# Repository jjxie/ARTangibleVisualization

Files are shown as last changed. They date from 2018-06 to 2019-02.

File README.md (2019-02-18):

# Augmented physical visualization of home food consumption and nutrition

## Introduction
In this project, I took the context of tracking the amount of personal food consumption and nutrient intakes as the scenario for exploring a new interface and interactions with the help of connected sensors, actuators, and augmented reality (AR). The novel tangible interface consists of two physical data representations with overlay AR information, respectively present the amount of food weight and nutrients intake. To compare how well the tangible interface performs in helping people in the context of gaining insight from the amount of food consumption and nutrients intake, a comparable screen interface is designed and developed. The screen interface is a webpage on the desktop with the same functionalities as the tangible interface, but with different interactions.
<br/>Check here for detailed information: https://jjxie8.wixsite.com/thinkbig/master-thesis-project.

## The settings of the project
This Project runs Socket IO client sides on two ESP32 boards and server side on the index.js.<br />Keywords: Socket.io, Arduino IDE, Webcam, A-Frame, AR.js Marker Trainning, Javascript, Bootstrap, Chart.js, Sketch 3D printing / Laser cutting, Card boards.

The sensors and materials used:
- Three ESP32 boards. 
- Five load cells and five HX711 amplifiers to measure food weight.
- Ten linear servos (SG90) + ten 3D models. Five sets represent food weight. Another five sets represent the amount of daily nutrients intake. The height of a rack of a 3D model represent a food weight data or the amount of a nutreint intake. 
The 3D model files from https://github.com/tscha70/3DPrinterSTLFiles/tree/master/win-D/STL-Parts with minor modifications.
- Five touch sensors are used to do selection of food to show detailed AR information. (using AR.js) 
- Five distance sensors (VL6180) which enable users to interact with the food weight data and see the simulated food consumption and nutrition intakes 

## Video prototype
- A video of the tangible interface prototype on Youtube: <br /> 
<a href="http://www.youtube.com/watch?feature=player_embedded&v=QyQpSfhoo6U
" target="_blank">The tangible interface</a>          
- A video of comparing screen interface prototype on Youtube: <br/>
 <a href="http://www.youtube.com/watch?feature=player_embedded&v=5_SD-PaekHA
" target="_blank">The screen interface</a>

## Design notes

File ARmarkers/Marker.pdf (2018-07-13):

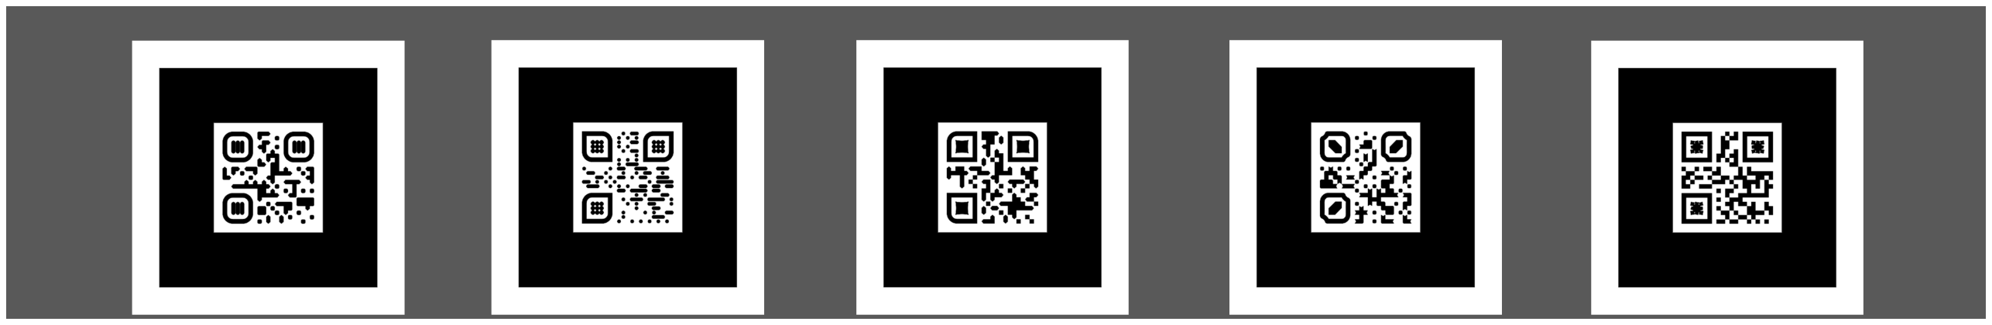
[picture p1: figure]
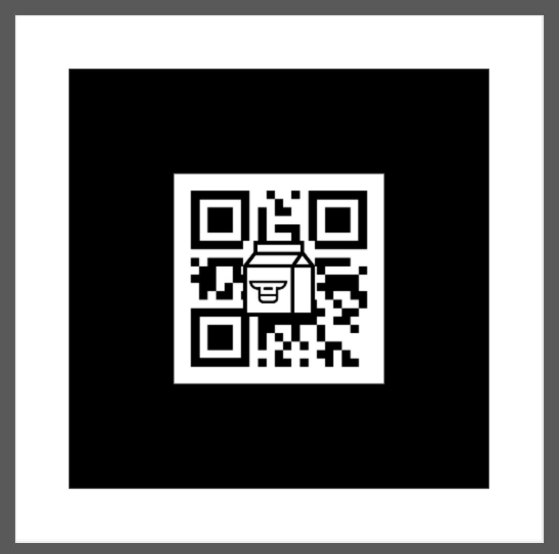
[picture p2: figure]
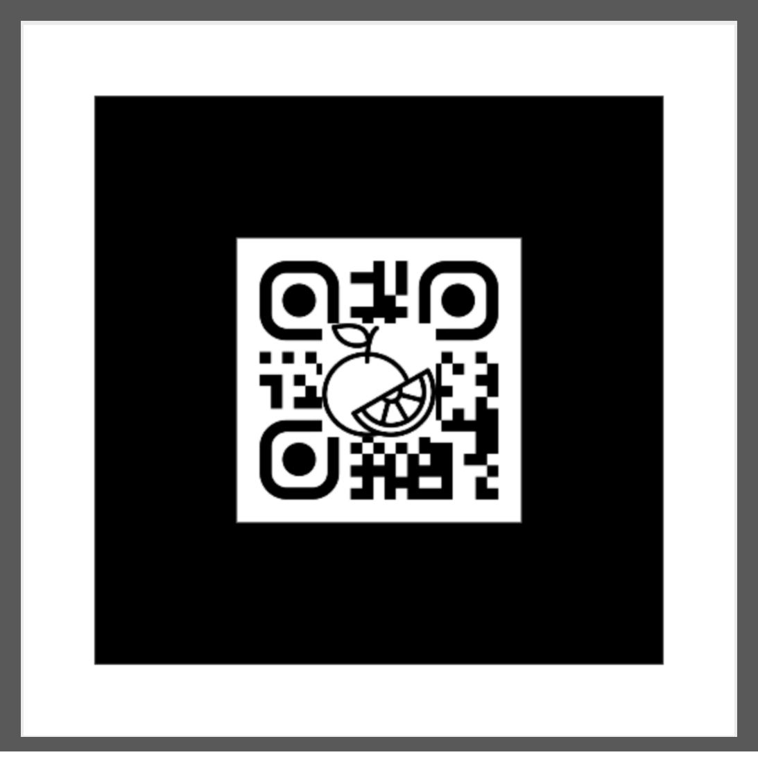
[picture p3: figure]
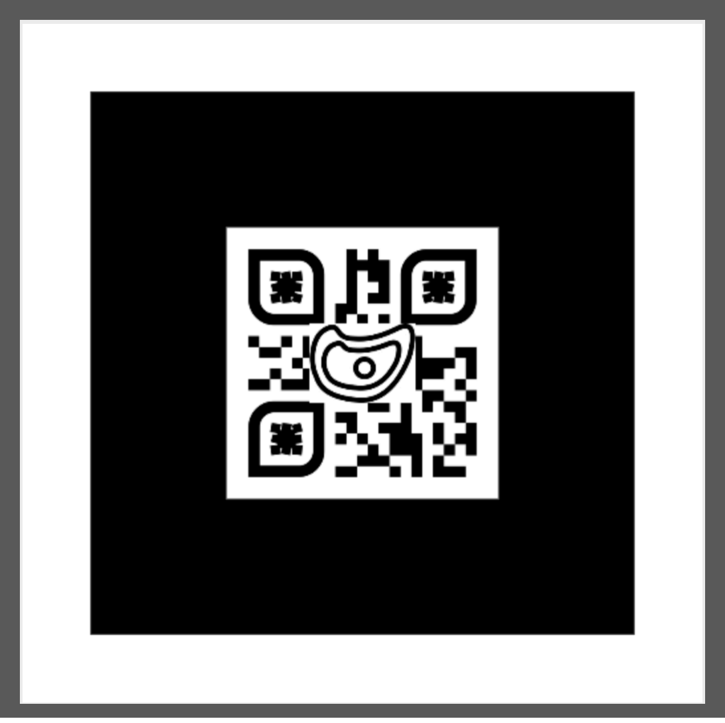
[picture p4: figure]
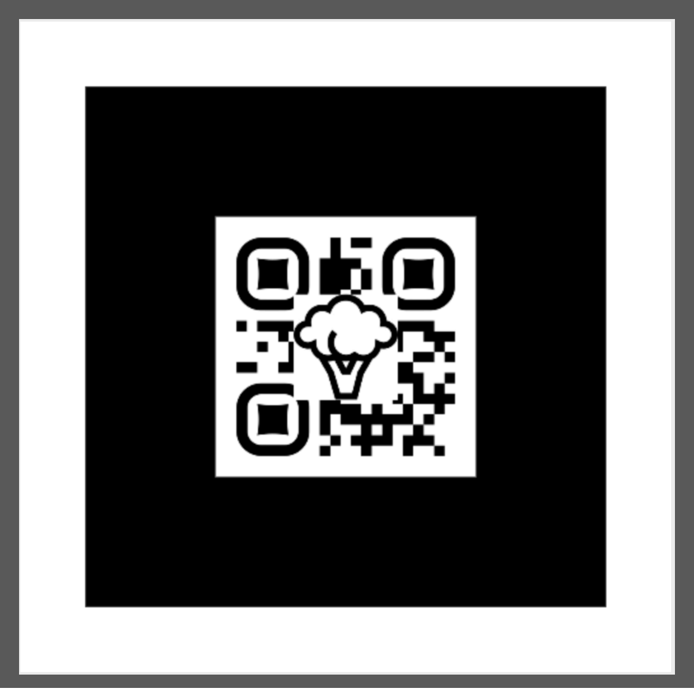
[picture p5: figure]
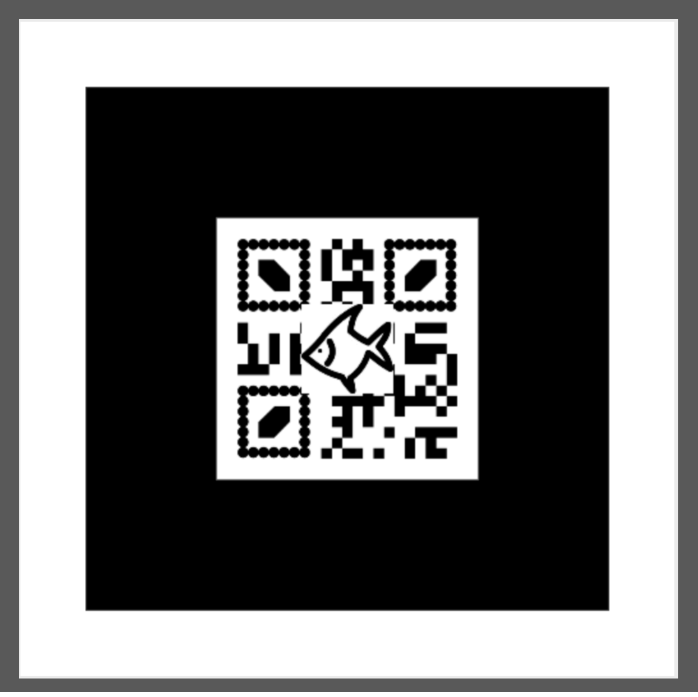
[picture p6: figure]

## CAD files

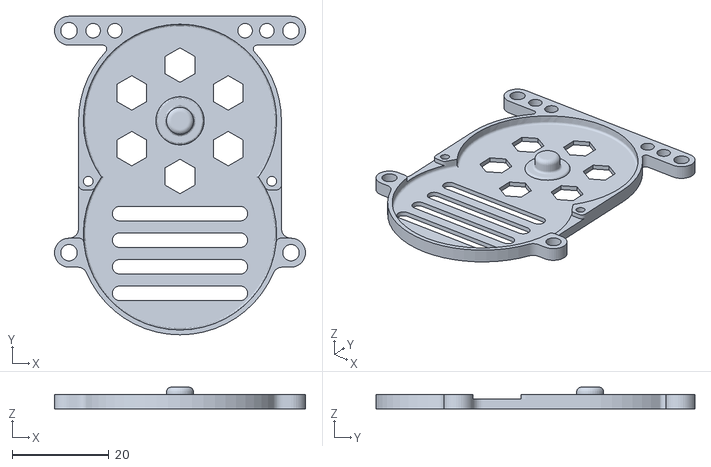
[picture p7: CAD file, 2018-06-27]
3D printing/wind-D_topplate.STL
52.0 x 65.9 x 4.50

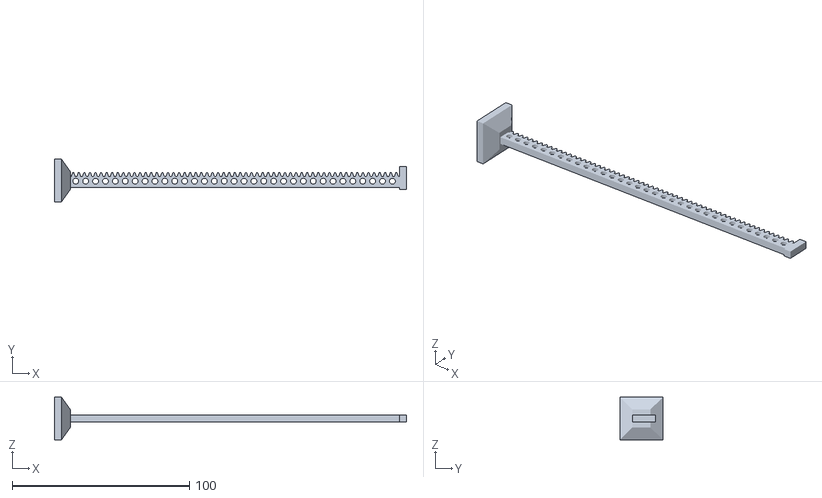
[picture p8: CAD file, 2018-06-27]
3D printing/rack1.stl
198.5 x 24.0 x 24.0

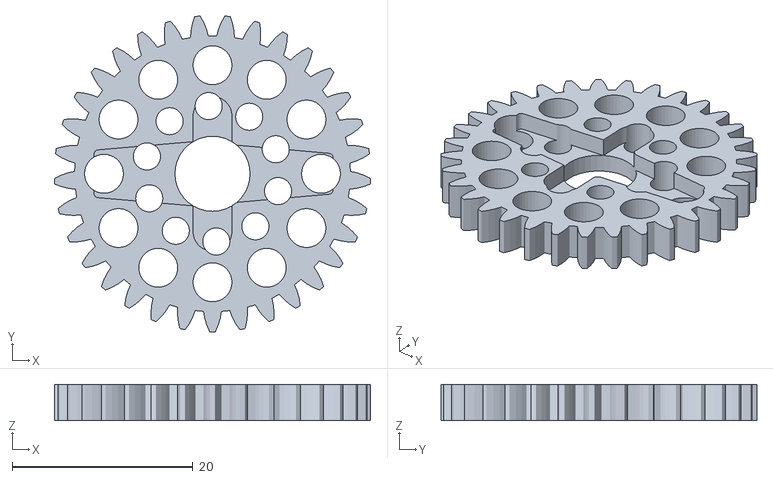
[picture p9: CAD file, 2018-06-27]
3D printing/wind-D_Gear33-1M-4mm_Servo.STL
35.0 x 34.9 x 4.00

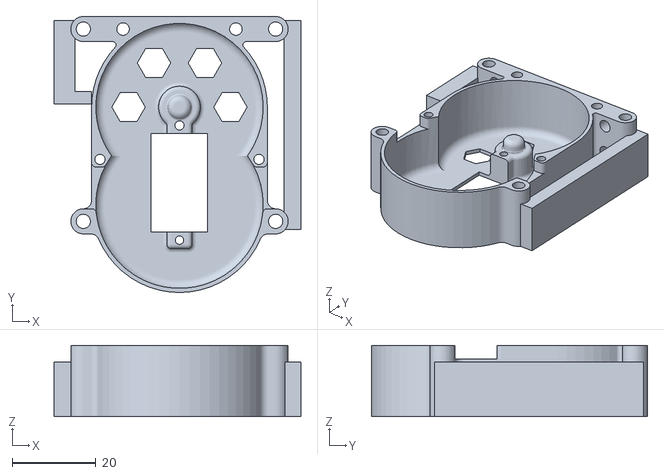
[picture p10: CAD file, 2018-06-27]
3D printing/base.stl
59.0 x 65.9 x 17.0

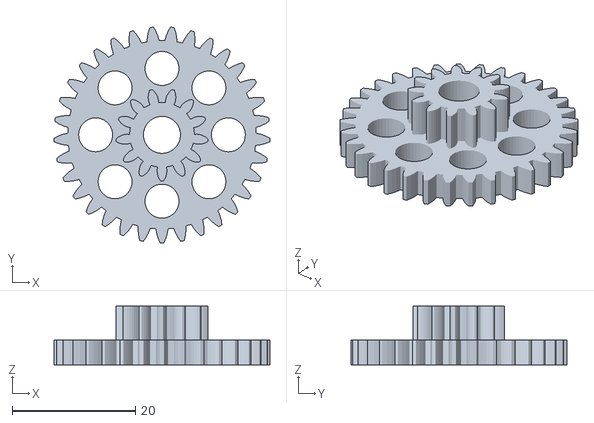
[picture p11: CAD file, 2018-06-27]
3D printing/wind-D_GearNormal.STL
35.0 x 34.9 x 9.50

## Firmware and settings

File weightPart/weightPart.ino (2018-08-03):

/******************************************************************************
   SparkFun_VL6180X, https://github.com/sparkfun/SparkFun_ToF_Range_Finder-VL6180_Arduino_Library

   Multiple VL6180 solution from https://learn.sparkfun.com/tutorials/vl6180-hookup-guide/discuss
   Add _i2caddress = new_address; to in Sparkfun_VL6180X.cpp in here:
   … VL6180x_setRegister(VL6180X_I2C_SLAVE_DEVICE_ADDRESS, new_address); i2caddress = new_address;
   return VL6180x_getRegister(VL6180X_I2C_SLAVE_DEVICE_ADDRESS); }

   Add one Euro filter to reduce distance reading jitter, http://cristal.univ-lille.fr/~casiez/1euro/

   SocketIoClient, have to comment // hexdump(payload, length); in the SocketIoClient.cpp file to avoid error.
   I2C: SDA 21  SCL 22

   Secure SSL connection, Socket.beginSSL("192.168.0.100", 3000);
 ******************************************************************************/
#define ESP32
#include <SocketIoClient.h>

#include <SF1eFilter.h>
#include <stdlib.h>
#include <time.h>
#include <stdio.h>
#include <Wire.h>
#include <math.h>
#include <ESP32_Servo.h>
#include <WiFi.h>

// The Router that the board connects to
const char* ssid = "TP-LINK_8F96";
const char* password = "49005875";

// socket.io connection
SocketIoClient socket;


// Published values for SG90 servos; adjust if needed
int minUs = 500;
int maxUs = 2400;

Servo servoMilk;
Servo servoOrange;
Servo servoMeat;
Servo servoBroccoli;
Servo servoFish;

// Define servo pins
int milkServoPin = 23;
int orangeServoPin = 18;
int meatServoPin = 27;
int broccoliServoPin = 32;
int fishServoPin= 12;

int servoStartDegree = 0;
float maxWeight = 1000;

// The full length of each servo
float servoMilkFullLength = 13.4;
float servoOrangeFullLength = 12.3;
float servoMeatFullLength = 12.3;
float servoBrocolliFullLength = 12.3;
float servoFishFullLength = 11.9;

// The length of per degree
float servoMilkLengthPerDegree = 0.087;
float servoOrangeLengthPerDegree = 0.072;
float servoMeatLengthPerDegree = 0.072;
float servoBrocolliLengthPerDegree = 0.072;
float servoFishLengthPerDegree = 0.06;

// The max degree of each servo
float servoMilkMaxDegree = 160;
float servoOrangeMaxDegree = 170;
float servoMeatMaxDegree = 170;
float servoBrocolliMaxDegree = 170;
float servoFishMaxDegree = 180;

// The received weight data
float milkWeight = 0.00;
float orangeWeight = 0.00;
float meatWeight = 0.00;
float brocolliWeight = 0.00;
float fishWeight = 0.00;

// The calculated degree
float milkDegree = 0.00;
float orangeDegree = 0.00;
float meatDegree = 0.00;
float brocolliDegree = 0.00;
float fishDegree = 0.00;


// Define touch sensor pins
int milkTouchPin = 19;
int orangeTouchPin = 17;
int meatTouchPin = 35;
int broccoliTouchPin = 33;
int fishTouchPin= 13;

// Selection status
boolean milkSelected = false;
boolean orangeSelected = false;
boolean meatSelected = false;
boolean broccoliSelected = false;
boolean fishSelected = false;

static unsigned long lastMillis = 0;


void setup() {
  // put your setup code here, to run once:
  Serial.begin(115200);
  Wire.begin();
  delay(100);

  // connect to wifi rounter in the environment
  Serial.print("Connecting to WiFi network ");
  Serial.println(ssid);
  WiFi.begin(ssid, password);
  while (WiFi.status() != WL_CONNECTED) {
    Serial.print(".");
    delay(500);
  }
  Serial.println("");
  Serial.println("Connected to the WiFi network");
  Serial.println("IP address: ");
  Serial.println(WiFi.localIP());

  // Begin a secure socket, find your computer WiFi TCP/IP Address
  // Mac Network--> WiFi--> Advanced--> TCP/IP 192.168.0.101
  socket.beginSSL("192.168.0.101", 3000);
  delay(100);

  socket.on("connect", socketConnected);

  // Servos
  servoMilk.attach(milkServoPin, minUs, maxUs);
  servoOrange.attach(orangeServoPin, minUs, maxUs);
  servoMeat.attach(meatServoPin, minUs, maxUs);
  servoBroccoli.attach(broccoliServoPin, minUs, maxUs);
  servoFish.attach(fishServoPin,minUs, maxUs);

  servoMilk.write(servoStartDegree);
  servoOrange.write(servoStartDegree);
  servoMeat.write(servoStartDegree);
  servoBroccoli.write(servoStartDegree);
  servoFish.write(servoStartDegree);


  // Touch sensors
  pinMode(milkTouchPin, INPUT);
  pinMode(orangeTouchPin, INPUT);
  pinMode(meatTouchPin, INPUT);
  pinMode(broccoliTouchPin, INPUT);
  pinMode(fishTouchPin, INPUT);

  delay(100);
}

void loop()
{
  socket.loop();
  socket.on("connect", socketConnected);
  
  // Receive milk weight data and rotate servo
  socket.on("scaleDataMilk", setMilkServo);
  // Receive orange weight data, rotate servo
  socket.on("scaleDataOrange", setOrangeServo);
  // Receive meat weight data, rotate servo
  socket.on("scaleDataMeat", setMeatServo);
  // Receive broccoli weight data, rotate servo
  socket.on("scaleDataBroccoli", setBroccoliServo);
  // Receive fish weight data, rotate servo
  socket.on("scaleDataFish", setFishServo);

  // Read milk touch sensor pins, emit 1 when touch the sensor
  boolean milkTouch = digitalRead(milkTouchPin);
  if (milkTouch != milkSelected) {
    milkSelected = milkTouch;
    if (milkTouch) socket.emit("milk", "\"1\"");
  }
  // Read orange touch sensor pins value and set status
  boolean orangeTouch = digitalRead(orangeTouchPin);
  if (orangeTouch != orangeSelected) {
    orangeSelected = orangeTouch;
    if (orangeTouch) socket.emit("orange", "\"1\"");
  }
  // Read meat touch sensor pins value and set status
  boolean meatTouch = digitalRead(meatTouchPin);
  if (meatTouch != meatSelected) {
    meatSelected = meatTouch;
    if (meatTouch) socket.emit("meat", "\"1\"");
  }
  // Read broccoli touch sensor pins value and set status
  boolean broccoliTouch = digitalRead(broccoliTouchPin);
  if (broccoliTouch != broccoliSelected) {
    broccoliSelected = broccoliTouch;
    if (broccoliTouch) socket.emit("broccoli", "\"1\"");
  }
  // Read fish touch sensor pins value and set status
    boolean fishTouch = digitalRead(fishTouchPin);
    if (fishTouch != fishSelected) {
      fishSelected = fishTouch;
      if (fishTouch) socket.emit("fish", "\"1\"");
    }

}


// Calculate the rotate degree based on (received weight data, the full length of the servo rack, the length per degree of the servo)
float calDegree(float weight, float fullLength, float lenghPerDegree) {
  float degree = round((weight / maxWeight * fullLength) / lenghPerDegree + 0.5);
  return degree;
}


// Socket IO functions
void socketConnected(const char *message, size_t length) {
  Serial.println("Board connects to server now!");
}

// Convenience functions to set servos; these are used as callbacks for the socket.io messages
void setMilkServo(const char *weight, size_t length) {
  servoMilk.attach(milkServoPin, minUs, maxUs);
  // get value from message
  String data;
  for (int i = 0; i < length; i++) {
    data += (char)weight[i];
  }
  int value = data.toInt();

  // calculate value for servo and send it
  float transformedValue = calDegree(value, servoMilkFullLength, servoMilkLengthPerDegree);
  //  attachAndSetServo(servoMilk,milkServoPin,transformedValue);
  Serial.print(value);
  Serial.print("  ");
  Serial.println(transformedValue);
  servoMilk.write(transformedValue); 
  delay(3000);
  servoMilk.detach();
}

void setOrangeServo(const char *weight, size_t length) {
  servoOrange.attach(orangeServoPin, minUs, maxUs);
  // get value from message
  String data;
  for (int i = 0; i < length; i++) {
    data += (char)weight[i];
  }
  int value = data.toInt();

  // calculate value for servo and send it
  float transformedValue = calDegree(value, servoOrangeFullLength, servoOrangeLengthPerDegree);
  //  attachAndSetServo(servoMilk,milkServoPin,transformedValue);
  Serial.print(value);
  Serial.print("  ");
  Serial.println(transformedValue);
  servoOrange.write(transformedValue);
  delay(3000);
  servoOrange.detach();
}

// Convenience functions to set servos; these are used as callbacks for the socket.io messages
void setMeatServo(const char *weight, size_t length) {
  servoMeat.attach(meatServoPin, minUs, maxUs);
  // get value from message
  String data;
  for (int i = 0; i < length; i++) {
    data += (char)weight[i];
  }
  int value = data.toInt();

  // calculate value for servo and send it
  float transformedValue = calDegree(value, servoMeatFullLength, servoMeatLengthPerDegree);
  Serial.print(value);
  Serial.print("  ");
  Serial.println(transformedValue);
  servoMeat.write(transformedValue);
  delay(3000);
  servoMeat.detach();
}

void setBroccoliServo(const char *weight, size_t length) {
  servoBroccoli.attach(broccoliServoPin, minUs, maxUs);
  // get value from message
  String data;
  for (int i = 0; i < length; i++) {
    data += (char)weight[i];
  }
  int value = data.toInt();

  // calculate value for servo and send it
  float transformedValue = calDegree(value, servoBrocolliFullLength, servoBrocolliLengthPerDegree);
  Serial.print(value);
  Serial.print("  ");
  Serial.println(transformedValue);
  servoBroccoli.write(transformedValue);
  delay(3000);
  servoBroccoli.detach();
}

void setFishServo(const char *weight, size_t length) {
  servoFish.attach(fishServoPin, minUs, maxUs);
  // get value from message
  String data;
  for (int i = 0; i < length; i++) {
    data += (char)weight[i];
  }
  int value = data.toInt();

  // calculate value for servo and send it
  float transformedValue = calDegree(value, servoFishFullLength, servoFishLengthPerDegree);
  Serial.println(transformedValue);
  servoFish.write(transformedValue);
  delay(3000);
  servoFish.detach();
}

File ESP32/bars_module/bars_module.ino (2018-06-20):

#define ESP32

#include <SparkFun_VL6180X.h>


#include <SocketIoClient.h>


#include <Wire.h>
#include <math.h>
#include <ESP32_Servo.h>


#include <WiFi.h>
const char* ssid = "TP-LINK_8F96";
const char* password = "49005875";

// comment the distance sensors out as long as their are not connected
//#define VL6180X_ADDRESS 0x29
//VL6180xIdentification identification;
//VL6180x sensor(VL6180X_ADDRESS);


// socket.io connection
SocketIoClient socket;


Servo servoMilk;
Servo servoOrange;
Servo servoMeat;
Servo servoBroccoli;
Servo servoFish;

int servoStartDegree = 0;
float maxWeight = 1000;

// The full length of each servo
float servoMilkFullLength = 13.4;
float servoOrangeFullLength = 12.3;
float servoMeatFullLength = 12.3;
float servoBrocolliFullLength = 12.3;
float servoFishFullLength = 11.9;

// The length of per degree
float servoMilkLengthPerDegree = 0.087;
float servoOrangeLengthPerDegree = 0.072;
float servoMeatLengthPerDegree = 0.072;
float servoBrocolliLengthPerDegree = 0.072;
float servoFishLengthPerDegree = 0.06;

// The max degree of each servo
float servoMilkMaxDegree = 160;
float servoOrangeMaxDegree = 170;
float servoMeatMaxDegree = 170;
float servoBrocolliMaxDegree = 170;
float servoFishMaxDegree = 180;

// The received weight data
float milkWeight = 0.00;
float orangeWeight = 0.00;
float meatWeight = 0.00;
float broccoliWeight = 0.00;
float fishWeight = 0.00;

// The calculated degree
float milkDegree = 0.00;
float orangeDegree = 0.00;
float meatDegree = 0.00;
float broccoliDegree = 0.00;
float fishDegree = 0.00;

// The servo pins
int milkServoPin = 8;
int orangeServoPin = 9;
int meatServoPin = 10;
int broccoliServoPin = 11;
int fishServoPin = 12;
 

// Define touch sensor pins
int milkTouchPin = 2;
int orangeTouchPin = 3;
int meatTouchPin = 4;
int broccoliTouchPin = 5;
int fishTouchPin = 6;

// Touch sensor value
int milkTouchValue = 0;
int orangeTouchValue = 0;
int meatTouchValue = 0;
int broccoliTouchValue = 0;
int fishTouchValue = 0;

// Touch sensor status
boolean milkSelected = false;
boolean orangeSelected = false;
boolean meatSelected = false;
boolean broccoliSelected = false;
boolean fishSelected = false;


// Distance
float milkRackDistance = 0.00;
float orangeRackDistance = 0.00;
float meatRackDistance = 0.00;
float broccoliRackDistance = 0.00;
float fishRackDistance = 0.00;

boolean servosConnected = false;

void setup() {
  // put your setup code here, to run once:
  Serial.begin(57600);
  delay(10);
    Serial.print("Connecting to WiFi network ");
    Serial.println(ssid);
  WiFi.begin(ssid, password);
  while (WiFi.status() != WL_CONNECTED) {
    Serial.print(".");
    delay(500);
  }
  Serial.println("");
  Serial.println("Connected to the WiFi network");
  Serial.println("IP address: ");
  Serial.println(WiFi.localIP());
  // the above line is the last one that is printed out on the serial monitor before the kernel panic

  
  Wire.begin();
  socket.begin("192.168.0.100", 3000);
  delay(100);

  //sensor.getIdentification(&identification); // Retrieve manufacture info from device memory
  //printIdentification(&identification); // Helper function to print all the Module information

  // Setting Distance sensor 
  //if(sensor.VL6180xInit() != 0){
  //  Serial.println("FAILED TO INITALIZE"); //Initialize device and check for errors
  //}; 
  //sensor.VL6180xDefautSettings(); //Load default settings to get started.
  //delay(1000); // delay 1s

  // Servos
  if (servosConnected){
  servoMilk.attach(8);
  servoOrange.attach(9);
  servoMeat.attach(10);
  servoBroccoli.attach(11);
  servoFish.attach(12);
  
  servoMilk.write(servoStartDegree);
  servoOrange.write(servoStartDegree);
  servoMeat.write(servoStartDegree);
  servoBroccoli.write(servoStartDegree);
  servoFish.write(servoStartDegree);
  }

  // Touch sensors
  pinMode(milkTouchPin, INPUT); 
  pinMode(orangeTouchPin, INPUT); 
  pinMode(meatTouchPin, INPUT); 
  pinMode(broccoliTouchPin, INPUT); 
  pinMode(fishTouchPin, INPUT); 

  // define socket io callbacks
  socket.on("connect", socketConnected);
  socket.on("scaleDataMilk", setMilkServo);
  //TODO: uncomment after functions are implemented
//  socket.on("scaleDataOrange", setOrangeServo);
//  socket.on("scaleDataMeat", setMeatServo);
//  socket.on("scaleDataBroccoli", setBroccoliServo);
//  socket.on("scaleDataFish", setFishServo);

}

void loop() 
{ 
  socket.loop();
  // we need to read the touch sensors and emit a socket.io message if a status changes
  boolean milk = digitalRead(milkTouchPin);
  if (milk != milkSelected) {
    milkSelected = milk;
    if (milk) socket.emit("Milk selection status", "\"1\"");
    if (!milk) socket.emit("Milk selection status", "\"0\"");
  }

  //TODO: do the same for the other 4 sensors























  // Read distance sensors, probably needs to use i2c addresses to indicate which sensor to query.
//  milkRackDistance =  sensor.getDistance();

}


// Calculate the degree based on 
// received weight data, the full length and the length per degree of the servo
float calDegree(float weight, float fullLength, float lenghPerDegree){
  float degree = round((weight/maxWeight * fullLength) / lenghPerDegree + 0.5);
  return degree;
}

// Convenience functions to set servos; these are used as callbacks for the socket.io messages
void setMilkServo(const char *weight, size_t length){
  // get value from message
  String data;
  for (int i = 0; i < length; i++) {
    data += (char)weight[i];
  }
  int value = data.toInt();

  // calculate value for servo and send it
  float transformedValue = calDegree(value, servoMilkFullLength, servoMilkLengthPerDegree);
  attachAndSetServo(servoMilk, milkServoPin, transformedValue);
}




//TODO: add functions for orange, meat, broccoli and fish



























void attachAndSetServo(Servo servo, int pin, int value) {
  servo.attach(pin);
  servo.write(value);
  servo.detach();
}


void socketConnected(const char *weight, size_t length){
  // get value from message
  Serial.println("Socket.io server connected.");
}

const char* printBoolean(boolean input){
  if (input) return("1");
  if (!input) return("0");
}

void printIdentification(struct VL6180xIdentification *temp){
  Serial.print("Model ID = ");
  Serial.println(temp->idModel);

  Serial.print("Model Rev = ");
  Serial.print(temp->idModelRevMajor);
  Serial.print(".");
  Serial.println(temp->idModelRevMinor);

  Serial.print("Module Rev = ");
  Serial.print(temp->idModuleRevMajor);
  Serial.print(".");
  Serial.println(temp->idModuleRevMinor);  

  Serial.print("Manufacture Date = ");
  Serial.print((temp->idDate >> 3) & 0x001F);
  Serial.print("/");
  Serial.print((temp->idDate >> 8) & 0x000F);
  Serial.print("/1");
  Serial.print((temp->idDate >> 12) & 0x000F);
  Serial.print(" Phase: ");
  Serial.println(temp->idDate & 0x0007);

  Serial.print("Manufacture Time (s)= ");
  Serial.println(temp->idTime * 2);
  Serial.println();
  Serial.println();
}

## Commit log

2018-03-28 Combine socket io with sensor data
2018-03-28 1. Support show sensor data on clients side when client is connected 2. Cannot real external css file
2018-03-28 Add a progress bar, the width value change based on sensor data
2018-03-28 1. Add a second sensor, and track its data 2. Change the style of progress of the first sensor
2018-03-29 1. Add a controller and its color is controlled by three other controllers 2. When a new client is connected, sometimes the sensor data will stuck, console has error setcolor is undefined, will check
    [index.js]
2018-03-30 1. Working prototype
2018-04-06 Change the variable name of sensor part to make it clear
2018-04-17 1. Connect wemos D1 mini with JS 2. Use Webduino sensor data control the blink frequency of wemos 3. Comment some interface code 4. Add AR markers file
2018-05-17 Change the client side with Arduino board. Keep the Wemos board code
2018-05-22 Add touch sensor data and AR view changes
    1. Add touch sensor part
    2. AR view changes according to the touch sensor as select or deselect
    data point
2018-05-22 Add touch sensor code and switch webduino to router wifi
2018-05-29 Serialport
    Adding serialport to the code, so can read Wemos serial data and broadcast this data using socket io.
2018-06-05 Broadcasting weight data
    Receive sensor data from wemos through serial port, and then broadcast the data to with different name to client(Arduino board) and html(AR)
2018-06-08 connect servo with calibration of the degree data
2018-06-12 Adding scale arduino data with one Euro filter
    Uploading arduino code which is run on Wemos D1 mini with four HX711+ load cell connected.
2018-06-13 Add arduino code
    1. the distance sensor part doesn't work.
    2. Add a test under loop Milk touch sensor
    [client.js]
2018-06-13 added code for esp32
2018-06-14 Scale arduino code update
    1. Each servo data has it's own 1 euro filter structure
    2. Chage the serial.begin
    3. Cancel delay between each servo read.
    4. Add logic, when data changes more than 3, then read more data. If two sequence readed data difference is smaller than 1, then regard this data as current weight data, serial print.
2018-06-18 Add mulitiple distance sensors with One euro filter
2018-06-20 arduino file for the ESP32 boards
    There are several todo items left to implement functions for the other food items.
    The board crashes and reboots after the wifi connection is established. Needs debugging.
    [bars_module.ino]
2018-06-21 ESP32 Socket io
    1. Connect ESP32 board with index.js
    2. Webcam is not working due to serve change to 192.168.0.100:3000, not secure.
    [index.js]
2018-06-22 Arduino socket io. Revise touch sensor and servo code
2018-06-26 Switch to secure connection and Weight Socket
    1. Switch to https
    2. Change to Socket.io to transfer weight data
2018-06-27 Scale arduino side can emit string data to server side
2018-06-27 Add servo range
    1. Add servo range which could let servo reach to right position. Without minUs and maxUs, the servo reach to wired position, like write(0), not in zero position.
    2. Distance sensors are not working. Sometimes can work. Need to check.
2018-06-27 Upload 3D models which work with Servos
    [base.stl, rack1.stl, wind-D_Gear33-1M-4mm_Servo.STL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]
2018-07-02 Add check to zero and jitter data in index.js
    [index.js]
2018-07-03 Slow down the ESP32 CPU in order to get stable weight data
    It is said from a post that the ESP32 is too fast for HX711, thus will output wierd data. After slow down the CPU, althoug the board processes much slower, but the data is much more accurate and stable. The resources: https://github.com/bogde/HX711/issues/75
2018-07-03 delay long before detach servo and calculate weight with distance data
2018-07-04 Add manually change weight code and seperate AR code
    1. Add manually changing weight code in both arduino and sever side. And show the new data on html
    2. Seperate AR and progress bar parts into two separate htmls. Preparing for testing.
2018-07-15 Nutrition calculate and save to history, add fish
    1. Add detection of day turning at midnight. Save current nutrition array data and yesterday to history json file, and then re intial nutrition array for the new day.
    2. Add fish parts code.
2018-07-18 Fix bug of showing virtual nutrients bar
    [index.js]
2018-07-18 Add a reset virtual button in the AR scene
    1. Currently cannot set the a-cursor position. It is bit annoying, because the reset button on the center of the screen. But works.
    [index.js]
2018-07-19 Design and implement screen version show history data and nutrients
    Two problems
    1. Cannot hide the area of history and nutrients space when nothing is selected
    2.Guess need callbacks to make sure the data is back. Sometimes click on milk for several times, just the data is not ready
    [index.js]
2018-07-20 Screen virtual nutrition bar and fix yesterdays two problems
    [index.js]
2018-07-25 Add code to set nutrients bar. Sperate weight part code to two ESP32
    Bug: Still get problem with distance sensors, sometimes cannot be initialized.
    [index.js, nutrientsPart.ino]
2018-07-27 Change attached pins to easy the assembly process
2018-07-30 Separate distance sensor part
    Because on ESP32, it always failed to initialize
    [index.js, weightPart.ino, weightScalePart.ino]
2018-08-01 fix bugs
    Problems are not fixed
    1. Hide virtual bars. When reset the weight bars, distance sensors are always detect new weight. Thus, the virtual bars will always show up, because the distance changes which refer to virtual weight changes.
    2. Also beacuse of the distance sensors, the virtual weight is always changing. Need two texts to seperate virtual and real weight.
    [index.js, weightPart.ino]
2018-08-02 Minor changes
    1. calibrate distace sensors again
    2. try add fish weight scale, but it still not working
    [weightScalePart.ino]
2018-08-03 Minor changes
    1. Round all the numbers
    2. Reset screen version weight after hide simulation
    3. Add simulate weight text for tangible version
    4. Change screen version + and - to 10g
    5. Fix fish servo bug
    [index.js, weightPart.ino]
2018-08-09 bug fix. Round screen version weight change number
    [index.js]
